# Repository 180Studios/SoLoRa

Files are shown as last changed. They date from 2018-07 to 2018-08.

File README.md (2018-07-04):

Board Features:

1. Low-cost components 

2. Easy (ish) Assembly. 
    a. Uses QFP package processor and 0603 Rs and Cs 
    b. Can be soldered by hand by most people using standard soldering iron 
    c. One exception is the accelerometer, which can be soldered using a reflow heat gun and a little training

3. Arduino compatible 
    a. Uses the same device as the Arduino Zero - can use Arduino bootloader. 

4. FeatherWing compatible 
    a. Can use with Adafruit’s featherwing expansion boards or use the header for a protoboard mezzanine 

5. Multiple power options to targeting wider IoT applications, particular field applications 
    a. Solar 
        i. Has a CR123 battery clip for a LiFePo4 battery used as a power reservoir. (400mAh) 
        ii. On-board regulator charges LiFePo4 to constant voltage. Solar cell size constrains max charge current. 
    b. Rechargeable Li-Po or external battery pack 
        i. For standard indoor applications 
        ii. On-board USB micro connector and charger IC 
    c. Lithium (primary cell) 
        i. Battery clip will also house a standard CR123 3V Lithium, which has ~1000mAH capacity 
    d. USB 5V for desktop development (or use with a USB battery bank?) 
    e. On- board adjustable regulator 
        i. Change Resistor values to adjust VDD 
            1. To drop Li-Po, external battery pack output voltage and USB 5V to safe level 
            2. LiFePo4 charge voltage. 
        ii. Regulator is used with Lithium primary battery 

6. Small size: 2.3 x 2 inches 
    a. Has mounting holes to match a inexpensive water tight enclosure 
    b. All components mount on one-size only. Bottom is free to increase mounting versatility. 
    c. 2-layer board, cheaper to fabricate. 

7. ARM Cortex M0 (SAMD20G18A) 

    a. Low power, high speed capable, 256K Flash 

8. Optional on-board sensors, indicators 
    a. 3-Axis Accelerometer 
    b. Temperature 
    c. Programmable Red LED 

9. Development Options 
    a. Arduino IDE (use as an Arduino Zero) 
    b. Atmel Studio 
        i. Atmel Studio has Arduino templates to program like Arduino, or: 
        ii. Use standard C form 
        iii. Full debugging capability (breakpoints, watch variables) 
            1. $20 JTAG debugger hardware required for this feature

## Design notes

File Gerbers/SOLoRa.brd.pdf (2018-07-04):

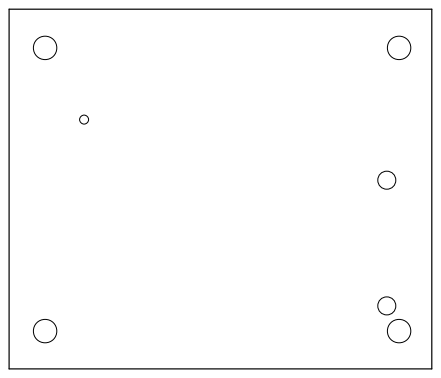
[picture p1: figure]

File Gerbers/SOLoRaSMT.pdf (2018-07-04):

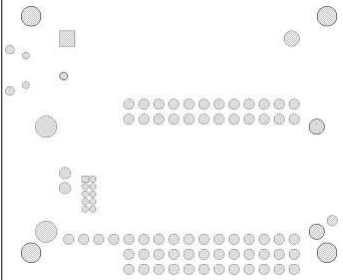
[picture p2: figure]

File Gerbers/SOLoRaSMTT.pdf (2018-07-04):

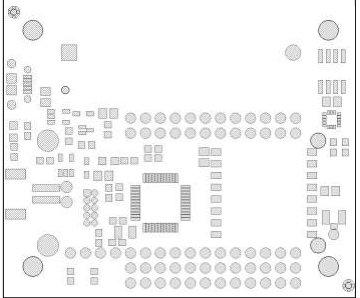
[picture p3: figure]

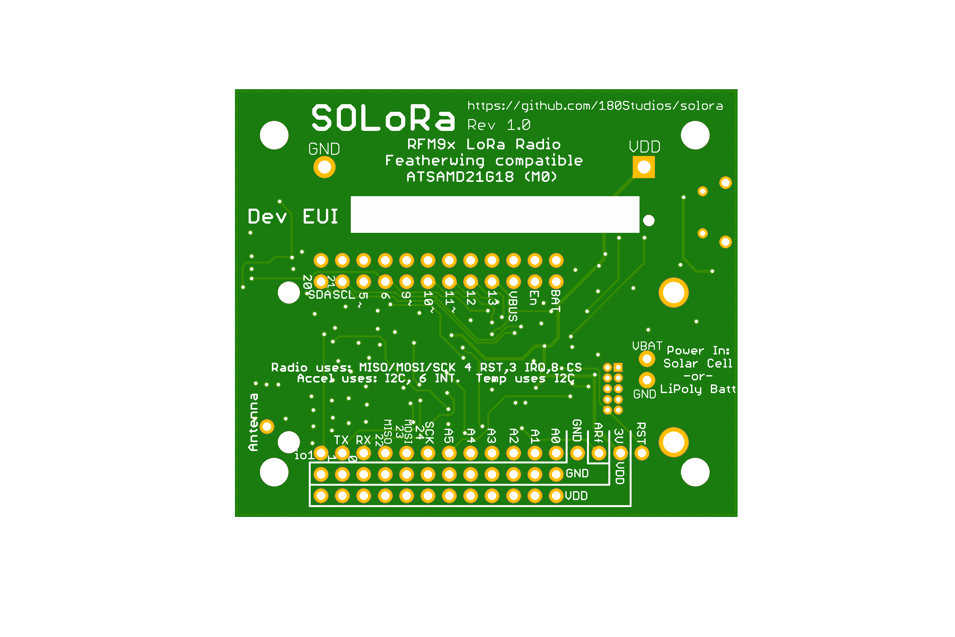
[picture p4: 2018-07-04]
Documentation/SOLoRa_BottomView.png

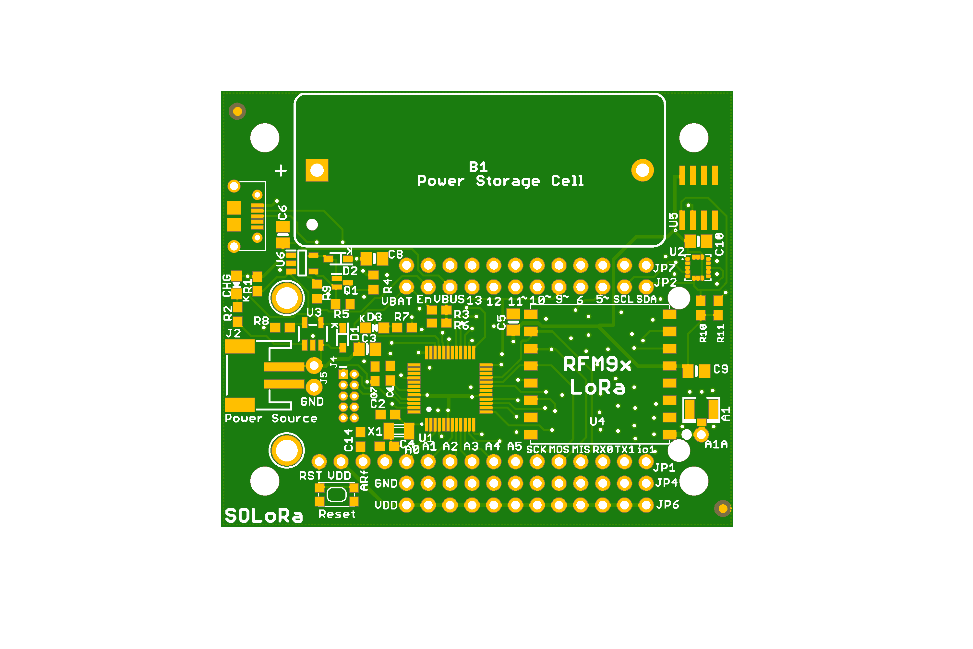
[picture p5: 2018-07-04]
Documentation/SOLoRa_TopView.png

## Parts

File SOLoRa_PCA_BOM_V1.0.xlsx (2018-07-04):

Part | Value | Device | Package | Description | BOM | DESCRIPTION | DIGI-KEY_PART_NUMBER | DIGI-KEY_PURCHASE_URL | HEIGHT | MANUFACTURER_NAME | MANUFACTURER_PART_NUMBER
A1 | U.FL Conn | ANTENNA_U.FL | U.FL | U.FL Antenna Connector
A1A | Pad for wire antenna | HEADER-1X1ROUND | 1X01_ROUND | PIN HEADER
B1 | BH123A | BH123A | BH123A
C1 | 1uF | CAP_CERAMIC0603_NO | 0603-NO | Ceramic Capacitors
C2 | 22pF | CAP_CERAMIC0603_NO | 0603-NO | Ceramic Capacitors
C3 | 10ÂµF | CAP_CERAMIC0805-NOOUTLINE | 0805-NO | Ceramic Capacitors
C4 | 22pF | CAP_CERAMIC0603_NO | 0603-NO | Ceramic Capacitors
C5 | 10uF | CAP_CERAMIC0805-NOOUTLINE | 0805-NO | Ceramic Capacitors
C6 | 10ÂµF | CAP_CERAMIC0805-NOOUTLINE | 0805-NO | Ceramic Capacitors
C7 | 1uF | CAP_CERAMIC0603_NO | 0603-NO | Ceramic Capacitors
C8 | 10ÂµF | CAP_CERAMIC0805-NOOUTLINE | 0805-NO | Ceramic Capacitors
C9 | 10uF | CAP_CERAMIC0805-NOOUTLINE | 0805-NO | Ceramic Capacitors
C10 | 10uF | CAP_CERAMIC0805-NOOUTLINE | 0805-NO | Ceramic Capacitors
C14 | 1uF | CAP_CERAMIC0603_NO | 0603-NO | Ceramic Capacitors
CHG | ORANGE | LED0805_NOOUTLINE | CHIPLED_0805_NOOUTLINE | LED
D1 | CUS520,H3F | CUS520,H3F | SOD2513X135N | Schottky Barrier Diode Silicon Epitaxial,Single Low Leakge, 30V 200mA Surface Mount USC |  | Schottky Barrier Diode Silicon Epitaxial,Single Low Leakge, 30V 200mA Surface Mount USC |  |  | 1.35mm | Toshiba | CUS520,H3F
D2 | CUS520,H3F | CUS520,H3F | SOD2513X135N | Schottky Barrier Diode Silicon Epitaxial,Single Low Leakge, 30V 200mA Surface Mount USC |  | Schottky Barrier Diode Silicon Epitaxial,Single Low Leakge, 30V 200mA Surface Mount USC |  |  | 1.35mm | Toshiba | CUS520,H3F
D3 | RED | LED0805_NOOUTLINE | CHIPLED_0805_NOOUTLINE | LED
H1 | STAND-OFF | STAND-OFF | STAND-OFF | Stand Off
H2 | STAND-OFF | STAND-OFF | STAND-OFF | Stand Off
H3 | STAND-OFF | STAND-OFF | STAND-OFF | Stand Off
H4 | STAND-OFF | STAND-OFF | STAND-OFF | Stand Off
J1 | CONN_USB-MIRCO_10118194 | CONN_USB-MIRCO_10118194 | 10118194_USB | CONN USB Micro Receptical SMT & PTH R/A Ampenol FCI 10118194-001LF
J2 | JSTPH | CON_JST_PH_2PIN | JSTPH2 | JST 2-Pin Right-Angle Connector
J4 | CORTEX_DEBUG_PTH | CORTEX_DEBUG_PTH | 2X5-PTH-1.27MM | Cortex Debug Connector - 10 pin
J5 |  | CONN_021X02_NO_SILK | 1X02_NO_SILK | Multi connection point. Often used as Generic Header-pin footprint for 0.1 inch spaced/style header connections
JP1 |  | HEADER-1X16ROUND | 1X16_ROUND | PIN HEADER
JP2 |  | HEADER-1X12 | 1X12_ROUND
JP4 |  | HEADER-1X12 | 1X12_ROUND
JP6 |  | HEADER-1X12 | 1X12_ROUND
JP7 |  | HEADER-1X12 | 1X12_ROUND
Q1 | RE1C002UNTCL | RE1C002UNTCL | SOT50P160X85-3N | MOSFET 1.2V Drive Nch MOSFET |  | MOSFET 1.2V Drive Nch MOSFET |  |  | 0.85mm | ROHM Semiconductor | RE1C002UNTCL
R1 | 100k | RESISTOR_0603_NOOUT | 0603-NO | Resistors
R2 | 1K | RESISTOR_0603_NOOUT | 0603-NO | Resistors
R3 | 220k | RESISTOR_0603_NOOUT | 0603-NO | Resistors
R4 | 383K | R-US_R0603 | R0603 | RESISTOR, American symbol
R5 | 133K | R-US_R0603 | R0603 | RESISTOR, American symbol
R6 | 100K | RESISTOR_0603_NOOUT | 0603-NO | Resistors
R7 | 2.2K | RESISTOR_0603_NOOUT | 0603-NO | Resistors
R8 | 22k | RESISTOR_0603_NOOUT | 0603-NO | Resistors
R9 | 220K | R-US_R0603 | R0603 | RESISTOR, American symbol
R10 | 2.2K | RESISTOR_0603_NOOUT | 0603-NO | Resistors
R11 | 2.2K | RESISTOR_0603_NOOUT | 0603-NO | Resistors
S1 | SPST_TACT-KMR2 | SPST_TACT-KMR2 | KMR2 | SMT 6mm switch, EVQQ2 series
U$31 | MOUNTINGHOLE2.5 | MOUNTINGHOLE2.5 | MOUNTINGHOLE_2.5_PLATED | Mounting Hole | EXCLUDE
U$32 | MOUNTINGHOLE2.5 | MOUNTINGHOLE2.5 | MOUNTINGHOLE_2.5_PLATED | Mounting Hole | EXCLUDE
U$34 | FIDUCIAL" | FIDUCIAL" | FIDUCIAL_1MM | Fiducial Alignment Points | EXCLUDE
U$35 | FIDUCIAL" | FIDUCIAL" | FIDUCIAL_1MM | Fiducial Alignment Points | EXCLUDE
U1 | ATSAMD21G18A-AUT | ATSAMD21G18A-AUT | QFP50P900X900X120-48N | Cortex-M0+, 256KB FLASH, 32KB SRAM, USB, DMA, T&R - 48TQFP IND TEMP, GREEN, 1.6-3.6V, 48MHz |  | MCU 32-bit SAM D21 ARM Cortex M0+ RISC 256KB Flash 3.3V 48-Pin TQFP T/R | ATSAMD21G18A-AUTCT-ND | https://www.digikey.com/product-detail/en/microchip-technology/ATSAMD21G18A-AUT/ATSAMD21G18A-AUTCT-ND/4878879
U2 | LIS3DETR | LIS3DETR | LGA16R50P5X3_300X300X100N | MEMS digital output motion sensor ultra low-power high performance 3-axes nano" accelerometer" |  | MEMS digital output motion sensor ultra low-power high performance 3-axes nano accelerometer | 497-16262-1-ND | https://www.digikey.com/product-detail/en/stmicroelectronics/LIS3DETR/497-16262-1-ND/5799914
U3 | MCP73831T-2ACI/OT | MCP73831/2 | SOT23-5 | MCP73831/2 LIPO Charger
U4 | RFM69HCW | RFM69HCW_SMT | RFMHCW_SMT | RFM69HCW - ISM Band RF Transceiver
U5 | LM75 | LM75 | SO8
U6 | NCP718ASNADJT1G | NCP718ASNADJT1G | SOT95P280X100-5N | LDO Regulator, 300 mA, Low Iq, Wide Input Voltage Adjustable, Active Discharge |  | LDO Regulator, 300 mA, Low Iq, Wide Input Voltage Adjustable, Active Discharge |  |  | 1mm | ON Semiconductor | NCP718ASNADJT1G
X1 | 32.768 | XTAL-3.2X1.5 | XTAL3215 | Low cost SMT crystals, no capacitors included

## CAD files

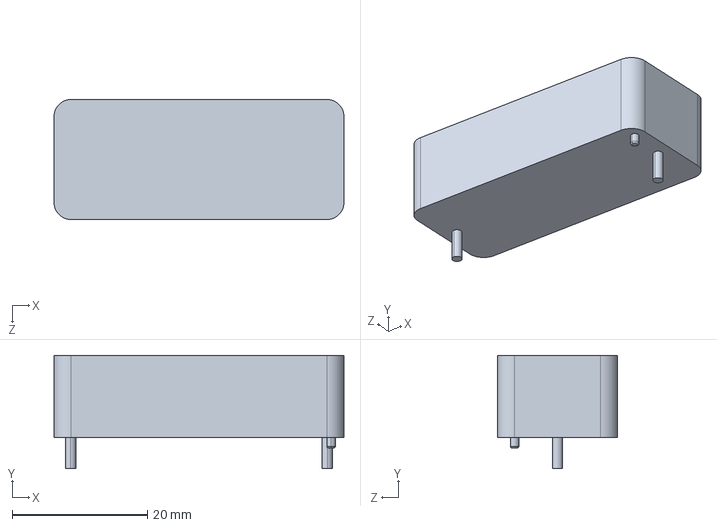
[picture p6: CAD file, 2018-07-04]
Documentation/Datasheets/BH123A.STEP
42.9 x 16.8 x 17.8 mm

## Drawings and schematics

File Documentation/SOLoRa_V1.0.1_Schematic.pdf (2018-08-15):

A

A

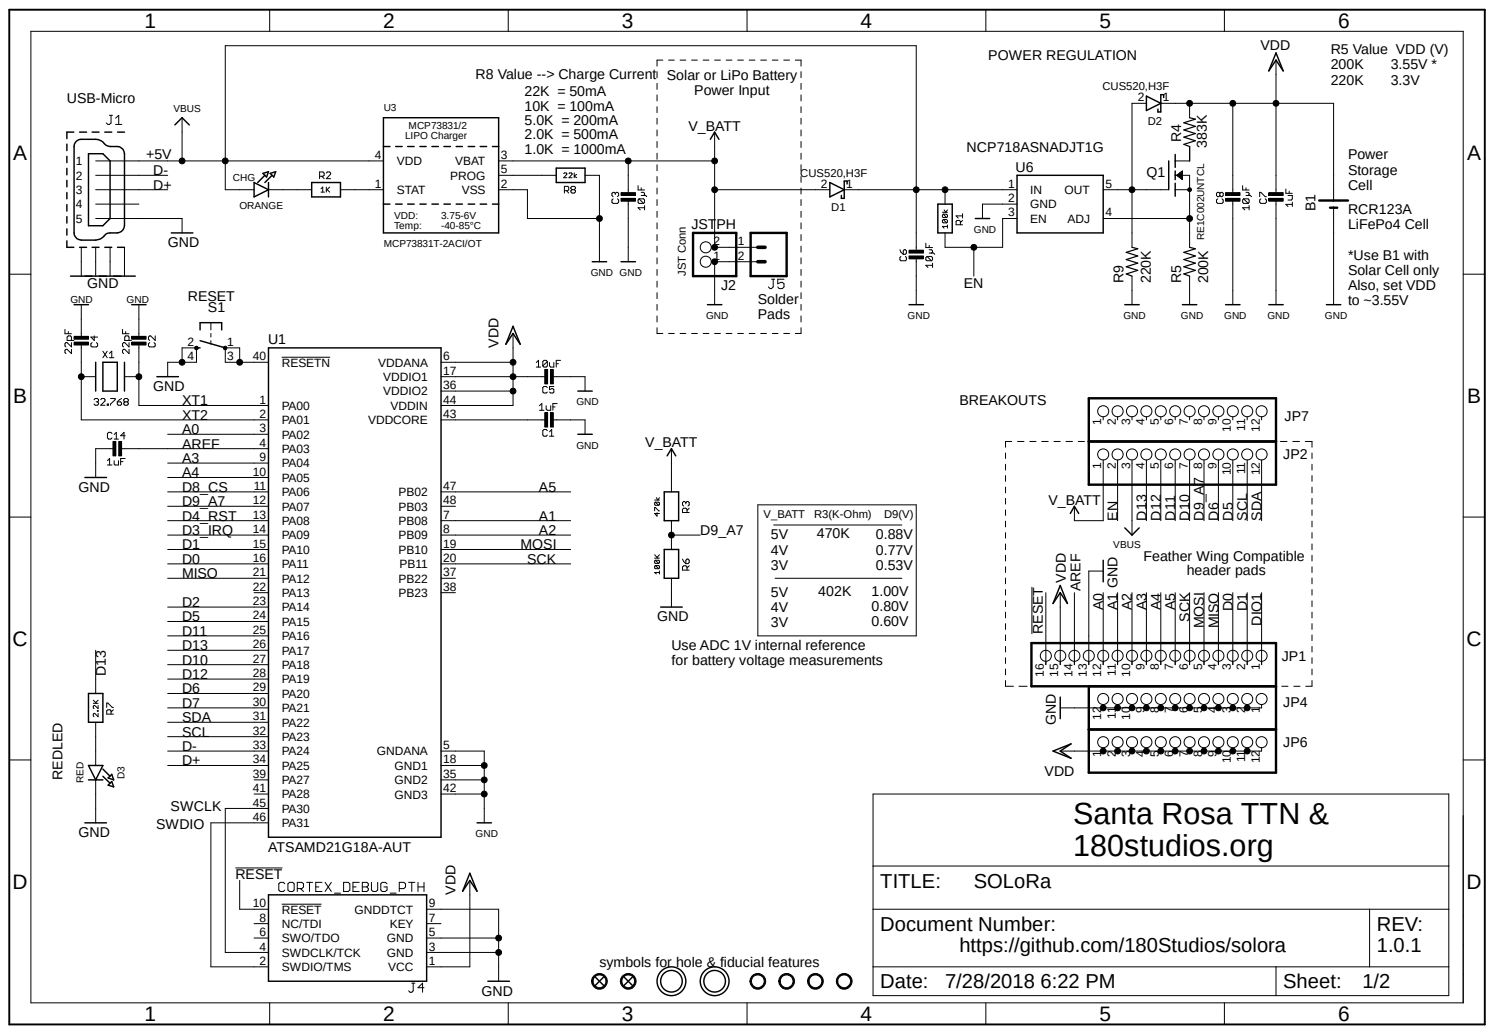
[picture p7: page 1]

Solar or LiPo Battery
Power Input

Use ADC 1V internal reference
for battery voltage measurements

Document Number: https://github.com/180Studios/solora | REV: 1.0.1

symbols for hole & fiducial features

Date: 7/28/2018 6:22 PM | Sheet: 1/2

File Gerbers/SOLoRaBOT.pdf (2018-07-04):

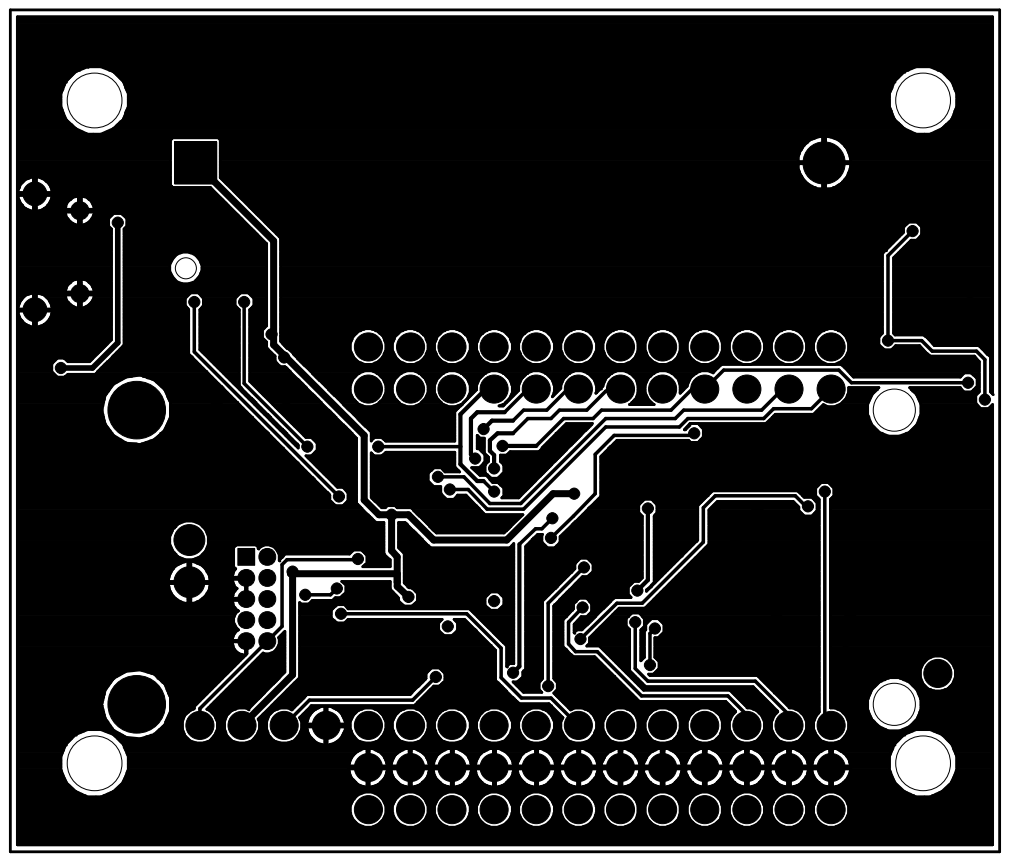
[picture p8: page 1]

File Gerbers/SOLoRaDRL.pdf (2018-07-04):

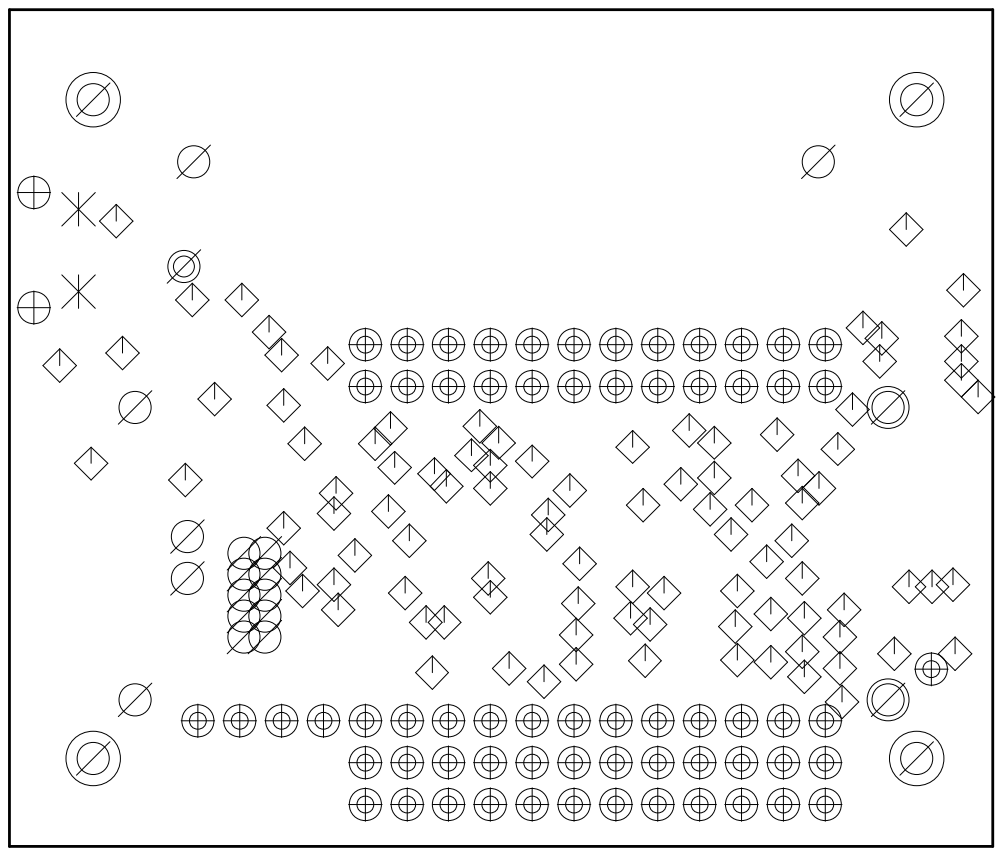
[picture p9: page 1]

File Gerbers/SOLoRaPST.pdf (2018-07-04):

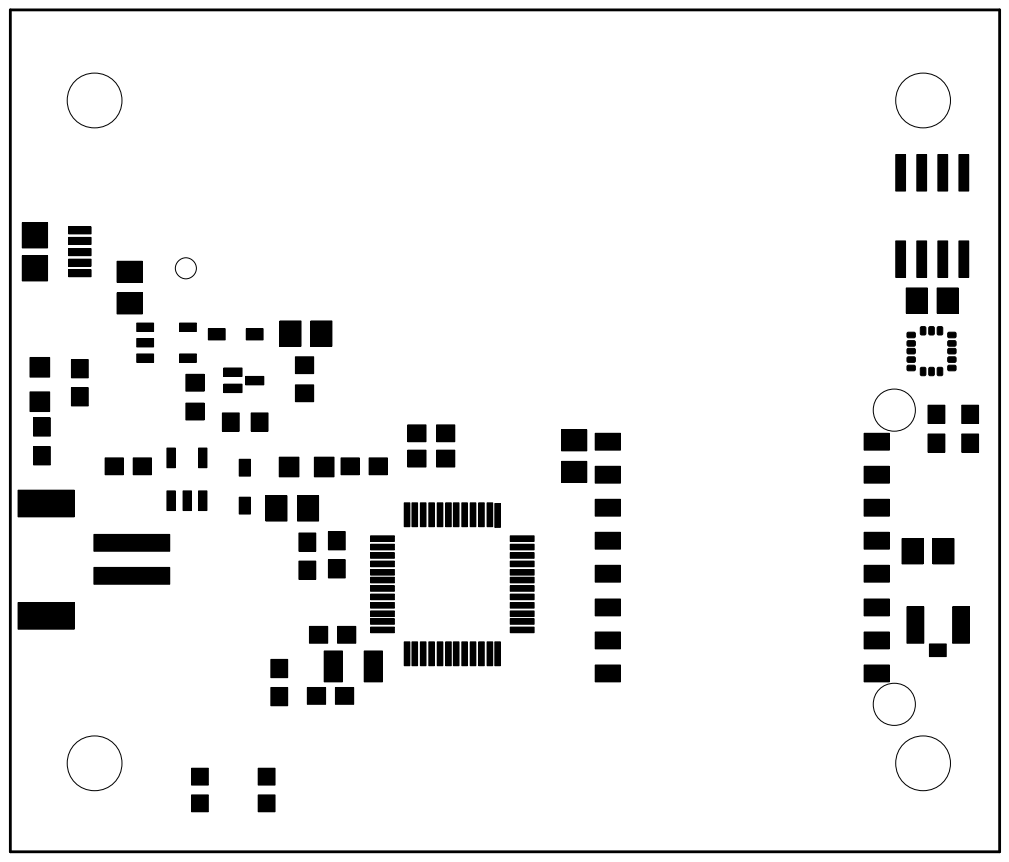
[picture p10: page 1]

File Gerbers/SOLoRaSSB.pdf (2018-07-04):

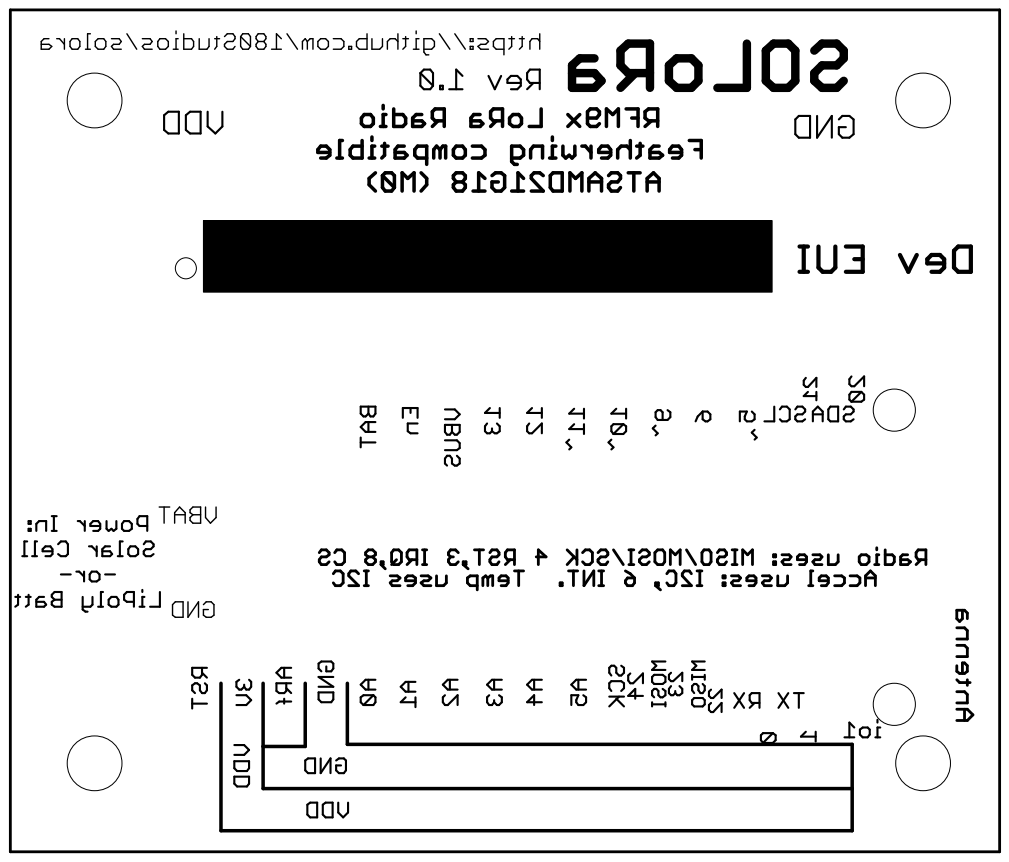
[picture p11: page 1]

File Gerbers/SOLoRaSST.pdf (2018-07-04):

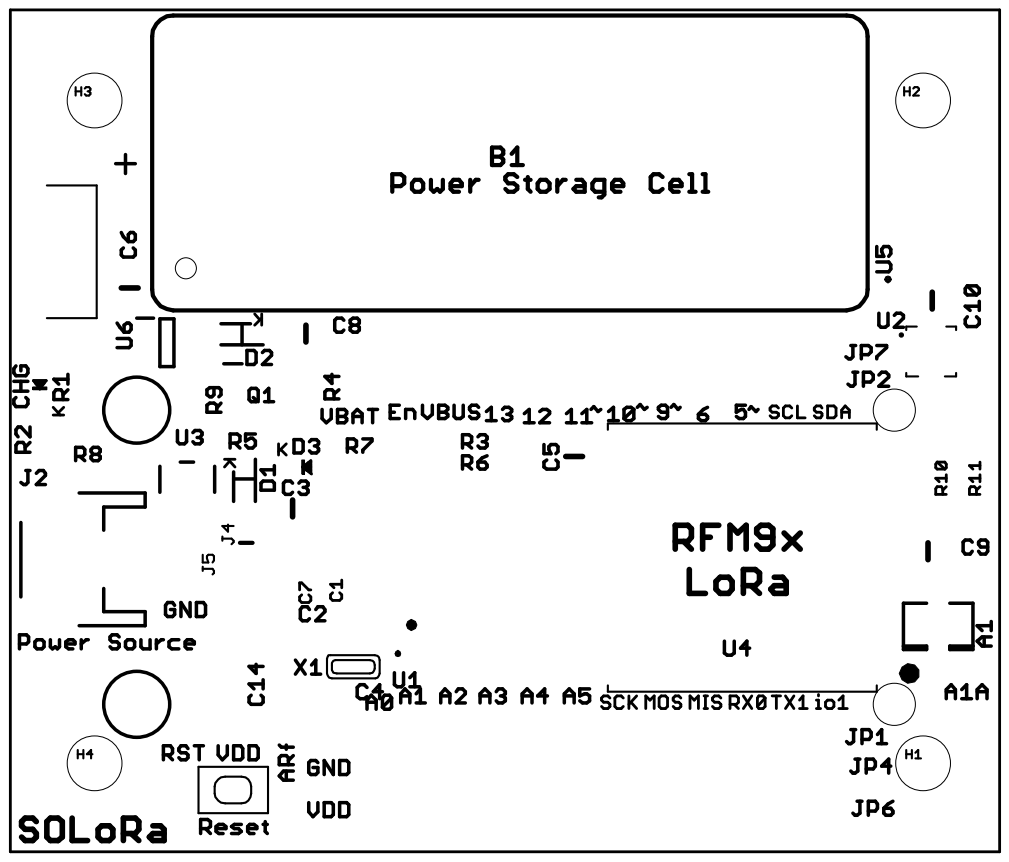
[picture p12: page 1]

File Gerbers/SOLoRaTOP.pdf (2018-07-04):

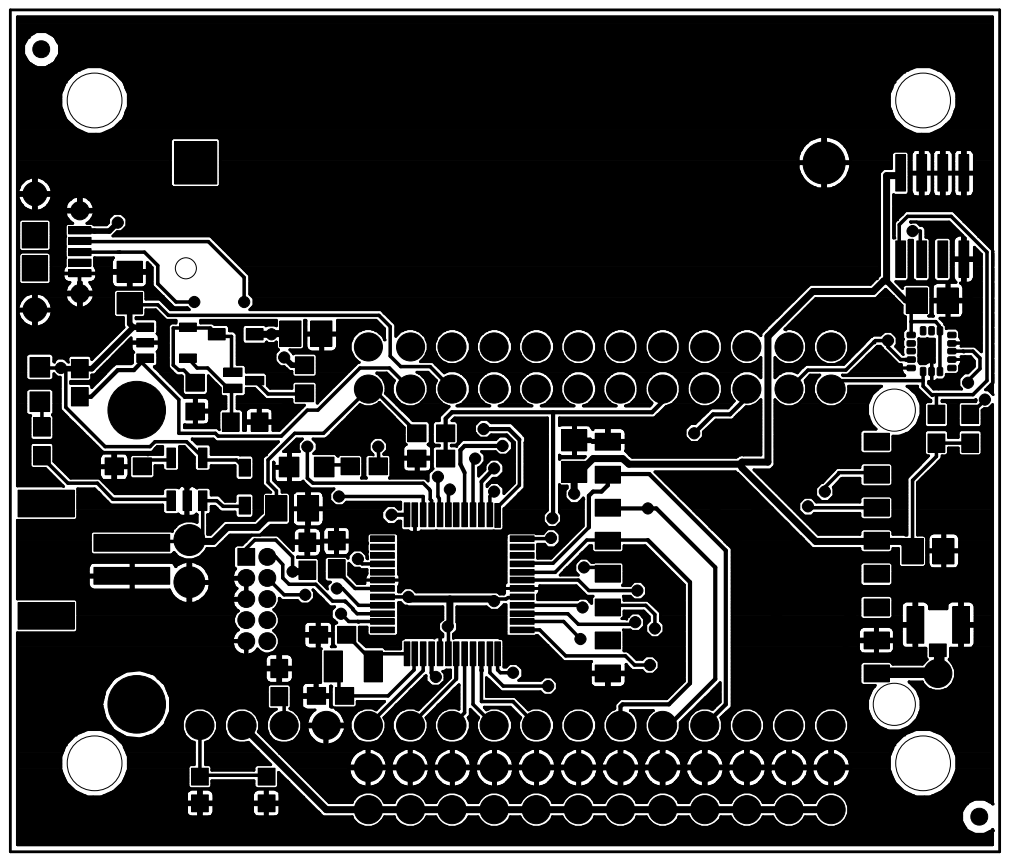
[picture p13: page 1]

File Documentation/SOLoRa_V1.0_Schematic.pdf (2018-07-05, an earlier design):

A

1 | 2 | 3 | 4 | 5 | 6

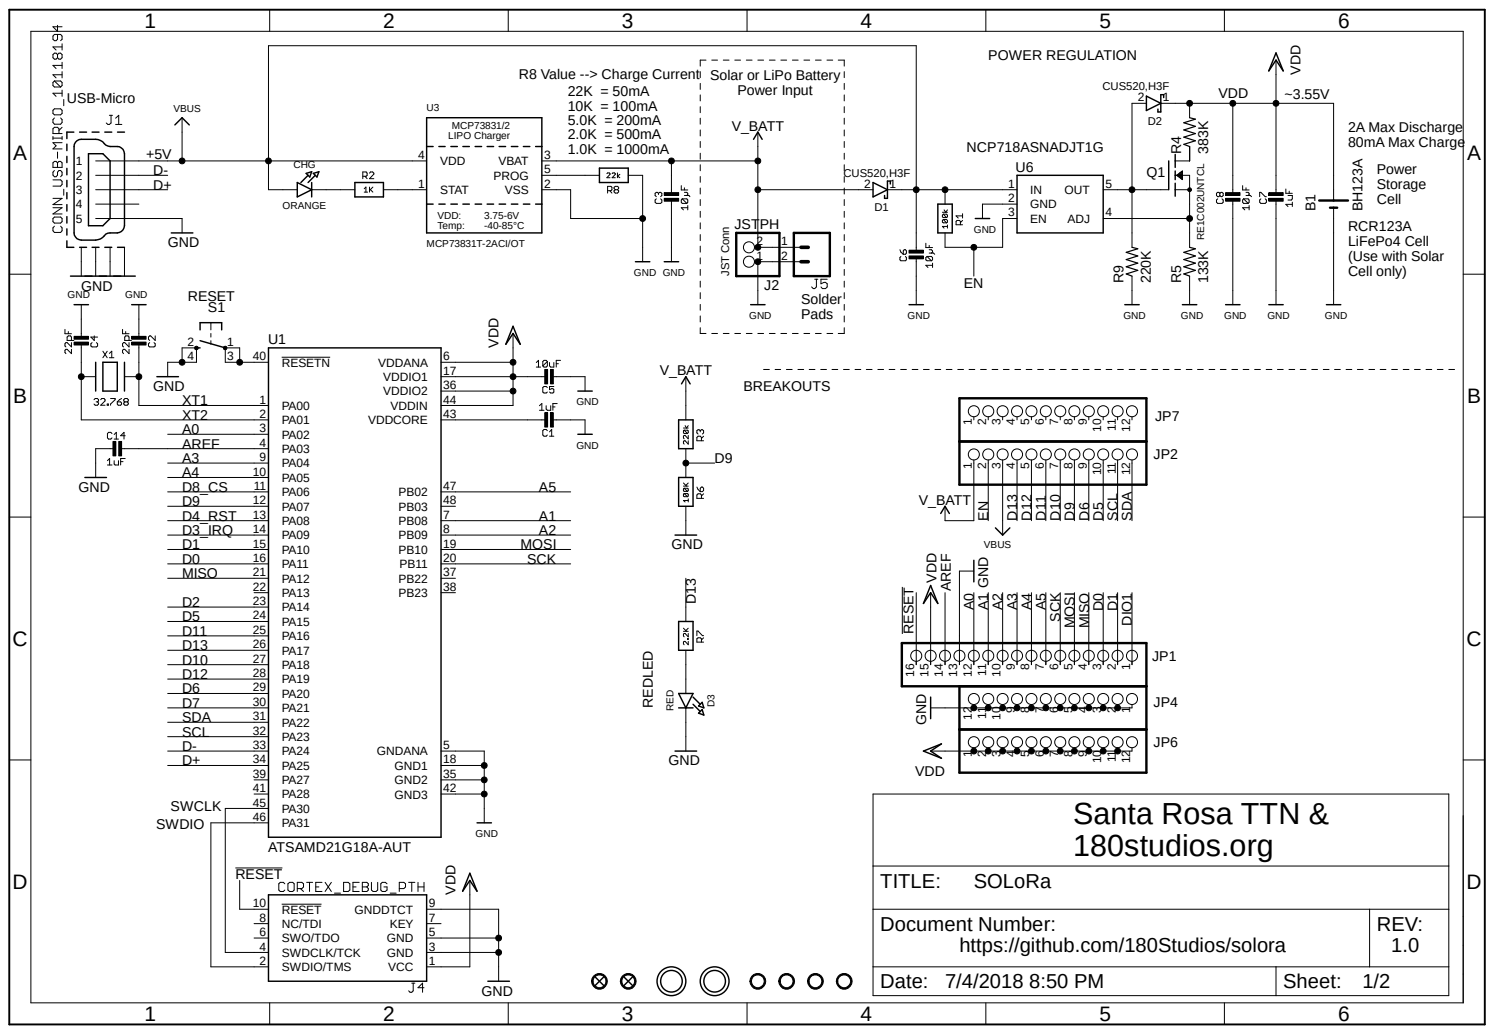
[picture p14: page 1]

Solar or LiPo Battery
Power Input

Document Number: https://github.com/180Studios/solora | REV: 1.0

Date: 7/4/2018 8:50 PM | Sheet: 1/2

## ABCD

## ABCD

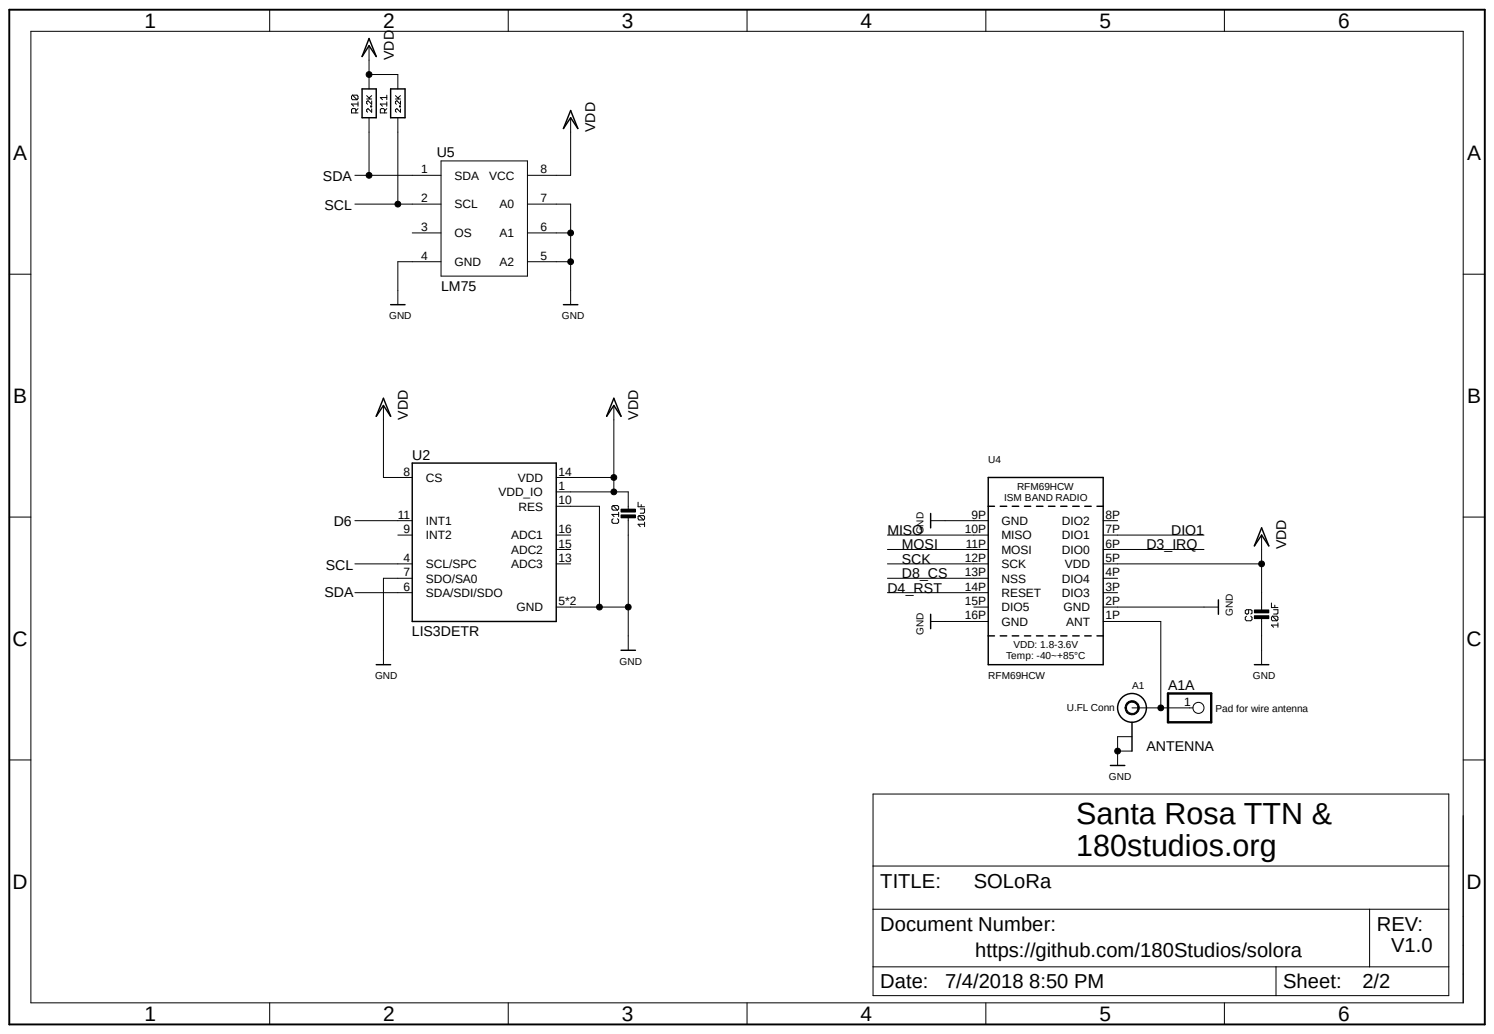
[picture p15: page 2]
GND; VDD; U.FL Conn; LIS3DETR; GND VDD; MISO 10P; DIO0; DIO2; DIO1; DIO5 15P; RESET 14P; GND 16P; ANT; 1P GND; 2P DIO3; MOSI 11P SCK 12P NSS 13P; RFM69HCW; DIO4; 4P VDD; GND 9P; VDD_IO; SCL/SPC; 5*2 SDA/SDI/SDO; SDO/SA0 7; INT2; RES; INT1 11; ADC3; ADC2; 15 ADC1; SDA; SCL; VCC; MOSI; MISO; SCK; D3_IRQ; D4_RST; RFM69HCW ISM BAND RADIO; VDD: 1.8-3.6V Temp: -40~+85°C; TITLE:; SOLoRa; ANTENNA

Pad for wire antenna

GND
Santa Rosa TTN &
180studios.org

Document Number: https://github.com/180Studios/solora | REV: V1.0

Date: 7/4/2018 8:50 PM | Sheet: 2/2

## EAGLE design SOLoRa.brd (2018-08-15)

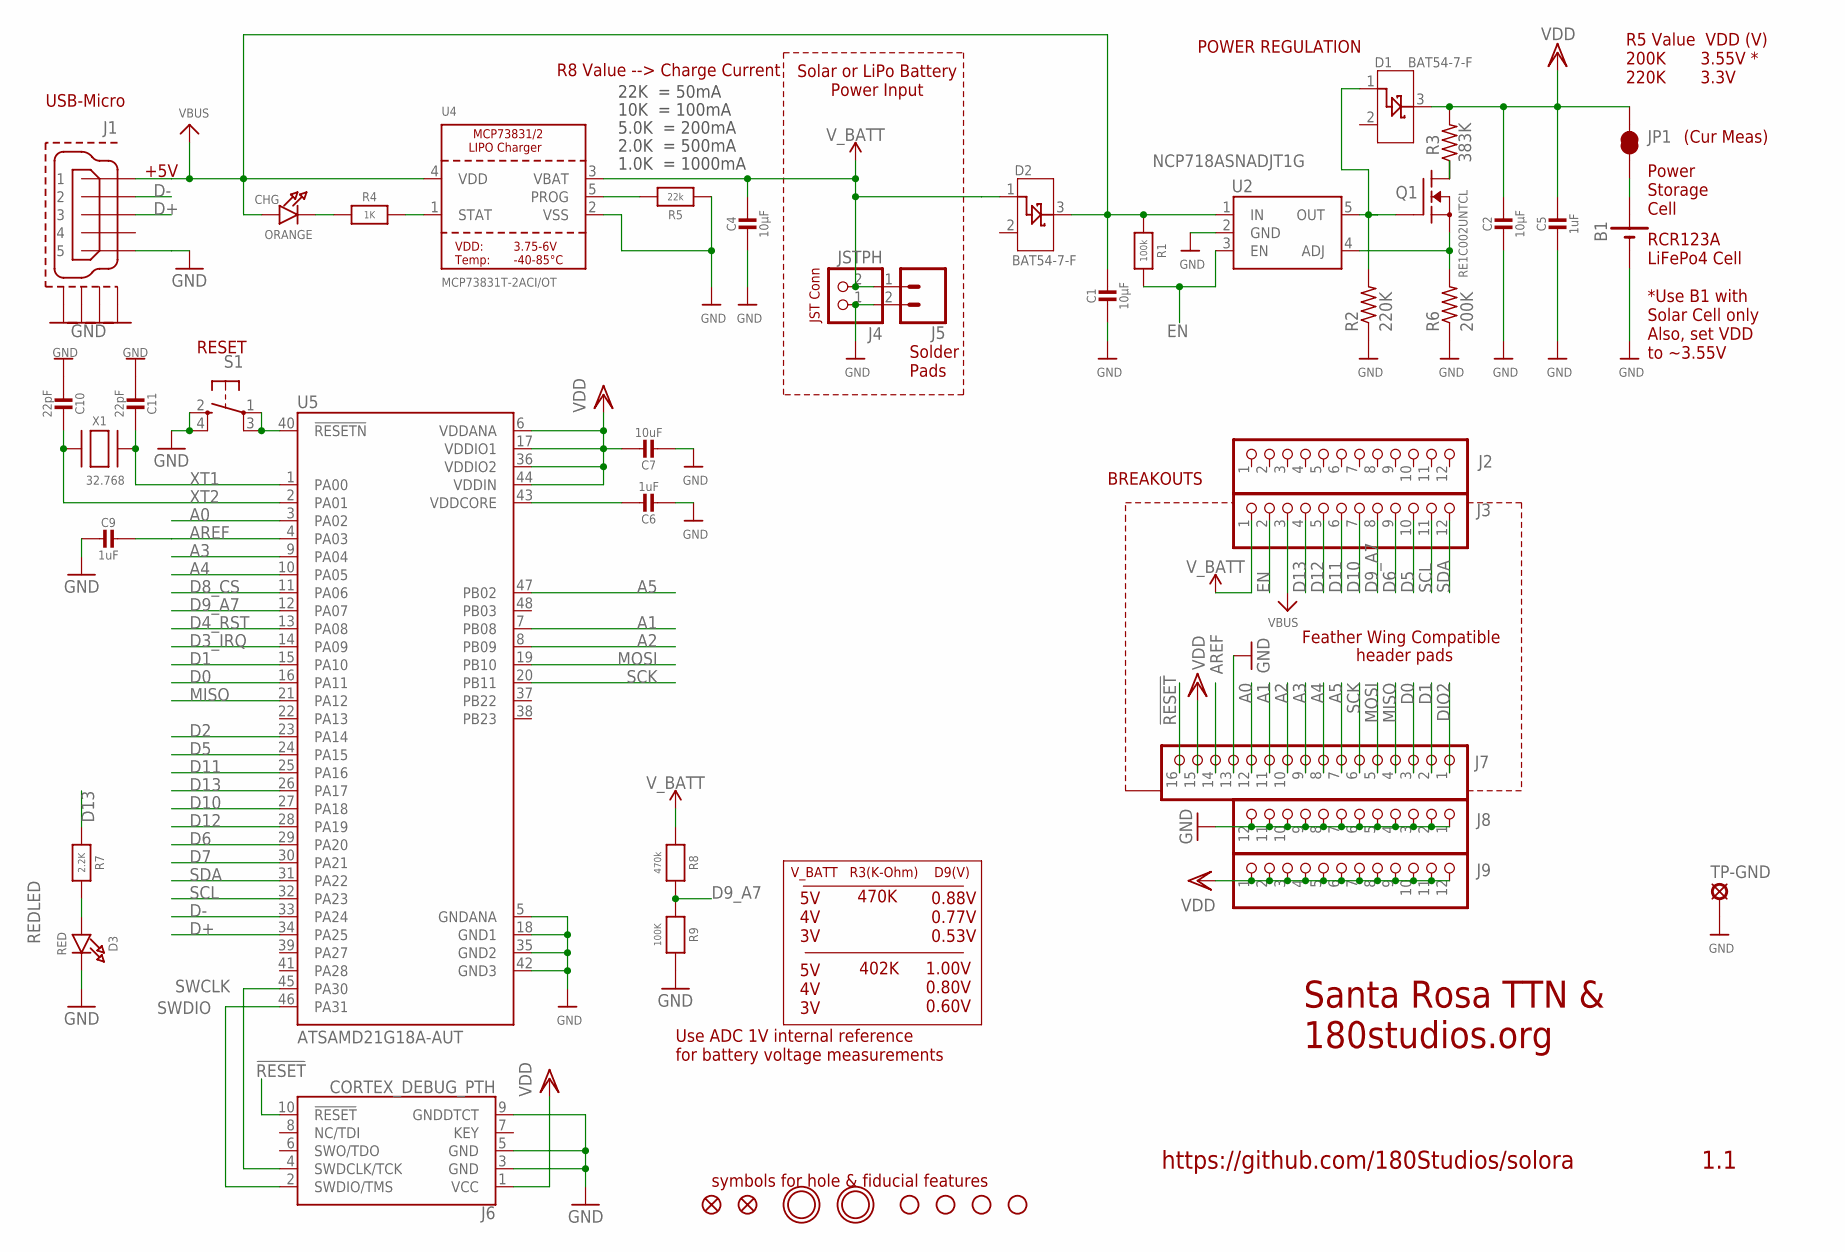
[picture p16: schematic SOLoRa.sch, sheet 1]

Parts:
$$U$1, $$U$4: FIDUCIAL""; FIDUCIAL_1MM
$$U$2, $$U$3: MOUNTINGHOLE2.5; MOUNTINGHOLE_2.5_PLATED
B1: BH123A
C1, C2, C4: 10µF; 0805-NO
C5, C6, C9: 1uF; 0603-NO
C7: 10uF; 0805-NO
C10, C11: 22pF; 0603-NO
CHG: ORANGE; CHIPLED_0805_NOOUTLINE
D1, D2: BAT54-7-F; SOT-23
D3: RED; CHIPLED_0805_NOOUTLINE
H1, H2, H3, H4: STAND-OFF
J1: CONN_USB-MIRCO_10118194; 10118194_USB
J2, J3, J8, J9: HEADER-1X12; 1X12_ROUND
J4: JSTPH; JSTPH2
J5: CONN_021X02_NO_SILK; 1X02_NO_SILK
J6: CORTEX_DEBUG_PTH; 2X5-PTH-1.27MM
J7: HEADER-1X16ROUND; 1X16_ROUND
JP1: JUMPER-SMT_2_NC_TRACE_NO-SILK; SMT-JUMPER_2_NC_TRACE_NO-SILK
Q1: RE1C002UNTCL; SOT50P160X85-3N
R1: 100k; 0603-NO
R2: 220K; R0603
R3: 383K; R0603
R4: 1K; 0603-NO
R5: 22k; 0603-NO
R6: 200K; R0603
R7: 2.2K; 0603-NO
R8: 470k; 0603-NO
R9: 100K; 0603-NO
S1: SPST_TACT-KMR2; KMR2
TP-GND: SE14
U2: NCP718ASNADJT1G; SOT95P280X100-5N
U4: MCP73831T-2ACI/OT; SOT23-5
U5: ATSAMD21G18A-AUT; QFP50P900X900X120-48N
X1: 32.768; XTAL3215

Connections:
!RESET: J6.10 (!RESET), J7.16, S1.1, S1.3 (P1), U5.40 (!RESETN)
A0: J7.12, U5.3 (PA02)
A1: J7.11, U5.7 (PB08)
A2: J7.10, U5.8 (PB09)
A3: J7.9, U5.9 (PA04)
A4: J7.8, U5.10 (PA05)
A5: J7.7, U5.47 (PB02)
ADJ1: Q1.3 (D), R3.1
AREF: C9.1, J7.14, U5.4 (PA03)
CHGLED: CHG.C, R4.1
D0: J7.3, U5.16 (PA11)
D1: J7.2, U5.15 (PA10)
D2: U5.23 (PA14)
D3_IRQ: U5.14 (PA09); also elsewhere on the board
D4_RST: U5.13 (PA08); also elsewhere on the board
D5: J3.10, U5.24 (PA15)
D6: J3.9, U5.29 (PA20); also elsewhere on the board
D7: U5.30 (PA21)
D8_CS: U5.11 (PA06); also elsewhere on the board
D9_A7: J3.8, R8.2, R9.1, U5.12 (PA07)
D10: J3.7, U5.27 (PA18)
D11: J3.6, U5.25 (PA16); also elsewhere on the board
D12: J3.5, U5.28 (PA19)
D13: J3.4, R7.1, U5.26 (PA17)
D+: J1.3, U5.34 (PA25)
D-: J1.2, U5.33 (PA24)
DIO2: J7.1; also elsewhere on the board
EN: J3.2, R1.2, U2.3 (EN)
GND: B1.MINUS, C1.2, C2.2, C4.2, C5.2, C6.2, C7.2, C9.2, C10.2, C11.2, D3.C, J1.5, J1.6 (GND1), J1.7 (GND2), J1.8 (GND3), J1.9 (GND4), J4.1, J5.2, J6.3 (GND), J6.5 (GND), J6.9 (GNDDTCT), J7.13, J8.1, J8.2, J8.3, J8.4, J8.5, J8.6, J8.7, J8.8, J8.9, J8.10, J8.11, J8.12, R2.1, R5.2, R6.1, R9.2, S1.2 (S), S1.4 (S1), TP-GND.MP, U2.2 (GND), U4.2 (VSS), U5.5 (GNDANA), U5.18 (GND1), U5.35 (GND2), U5.42 (GND3); also elsewhere on the board
MISO: J7.4, U5.21 (PA12); also elsewhere on the board
MOSI: J7.5, U5.19 (PB10); also elsewhere on the board
PLUS: B1.PLUS, JP1.1
PROG: R5.1, U4.5 (PROG)
REDLED: D3.A, R7.2
REGADJ: Q1.2 (S), R6.2, U2.4 (ADJ)
REGOUT: D1.1 (EPAD1), Q1.1 (G), R2.2, U2.5 (OUT)
SCK: J7.6, U5.20 (PB11); also elsewhere on the board
SCL: J3.11, U5.32 (PA23); also elsewhere on the board
SDA: J3.12, U5.31 (PA22); also elsewhere on the board
STAT: R4.2, U4.1 (STAT)
SWCLK: J6.4 (SWDCLK/TCK), U5.45 (PA30)
SWDIO: J6.2 (SWDIO/TMS), U5.46 (PA31)
VBUS: C1.1, CHG.A, D2.3 (EPAD3), J1.1, J3.3, R1.1, U2.1 (IN), U4.4 (VDD)
VDD: C2.1, C5.1, C7.1, D1.3 (EPAD3), J6.1 (VCC), J7.15, J9.1, J9.2, J9.3, J9.4, J9.5, J9.6, J9.7, J9.8, J9.9, J9.10, J9.11, J9.12, JP1.2, R3.2, U5.6 (VDDANA), U5.17 (VDDIO1), U5.36 (VDDIO2), U5.44 (VDDIN); also elsewhere on the board
VDDCORE: C6.1, U5.43 (VDDCORE)
V_BATT: C4.1, D2.1 (EPAD1), J3.1, J4.2, J5.1, R8.1, U4.3 (VBAT)
XT1: C11.1, U5.1 (PA00), X1.P$1
XT2: C10.1, U5.2 (PA01), X1.P$2

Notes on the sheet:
POWER REGULATION
RESET
10K = 100mA
5.0K = 200mA
2.0K = 500mA
1.0K = 1000mA
BREAKOUTS
R5 Value VDD (V) 200K 3.55V * 220K 3.3V
22K = 50mA
RCR123A LiFePo4 Cell *Use B1 with Solar Cell only Also, set VDD to ~3.55V
Solar or LiPo Battery Power Input
Power Storage Cell
JST Conn
Solder Pads
R8 Value --> Charge Current
1.1
Santa Rosa TTN & 180studios.org
https://github.com/180Studios/solora
USB-Micro
+5V
Feather Wing Compatible
header pads
V_BATT R3(K-Ohm) D9(V)
5V 4V 3V
470K
402K
0.88V 0.77V 0.53V
1.00V 0.80V 0.60V
Use ADC 1V internal reference for battery voltage measurements
symbols for hole & fiducial features
(Cur Meas)

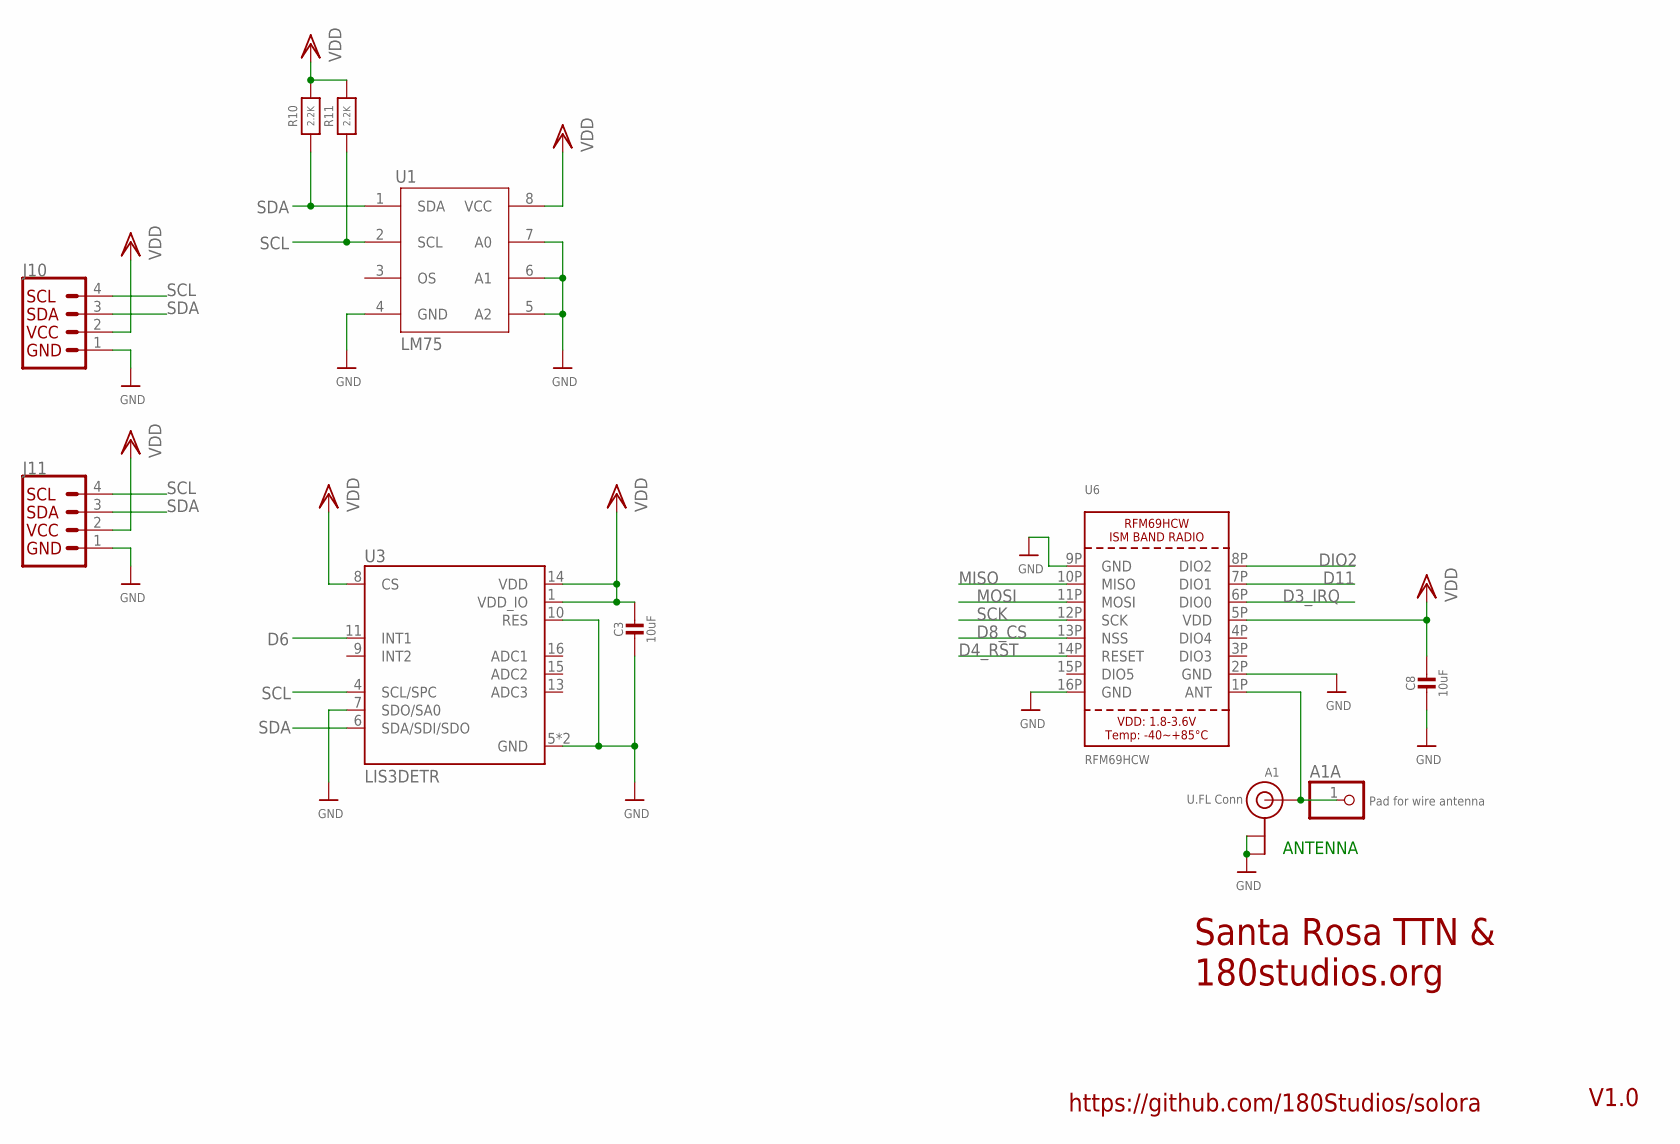
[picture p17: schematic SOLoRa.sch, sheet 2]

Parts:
A1: U.FL Conn; U.FL
A1A: Pad for wire antenna; 1X01_ROUND
C3, C8: 10uF; 0805-NO
J10, J11: QWIIC_CONNECTORJS-1MM; 1X04_1MM_RA
R10, R11: 2.2K; 0603-NO
U1: LM75; SO8
U3: LIS3DETR; LGA16R50P5X3_300X300X100N
U6: RFM69HCW; RFMHCW_SMT

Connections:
ANT: A1.3 (SIGNAL), A1A.1, U6.1P (ANT)
D3_IRQ: U6.6P (DIO0); also elsewhere on the board
D4_RST: U6.14P (RESET); also elsewhere on the board
D6: U3.11 (INT1); also elsewhere on the board
D8_CS: U6.13P (NSS); also elsewhere on the board
D11: U6.7P (DIO1); also elsewhere on the board
DIO2: U6.8P (DIO2); also elsewhere on the board
GND: A1.1 (GND), A1.2 (GND), C3.2, C8.2, J10.1, J11.1, U1.4 (GND), U1.5 (A2), U1.6 (A1), U1.7 (A0), U3.5 (GND), U3.7 (SDO/SA0), U3.10 (RES), U3.12 (GND), U6.2P (GND), U6.9P (GND), U6.16P (GND); also elsewhere on the board
MISO: U6.10P (MISO); also elsewhere on the board
MOSI: U6.11P (MOSI); also elsewhere on the board
SCK: U6.12P (SCK); also elsewhere on the board
SCL: J10.4, J11.4, R11.1, U1.2 (SCL), U3.4 (SCL/SPC); also elsewhere on the board
SDA: J10.3, J11.3, R10.1, U1.1 (SDA), U3.6 (SDA/SDI/SDO); also elsewhere on the board
VDD: C3.1, C8.1, J10.2, J11.2, R10.2, R11.2, U1.8 (VCC), U3.1 (VDD_IO), U3.8 (CS), U3.14 (VDD), U6.5P (VDD); also elsewhere on the board

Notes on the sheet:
ANTENNA
Santa Rosa TTN & 180studios.org
V1.0
https://github.com/180Studios/solora

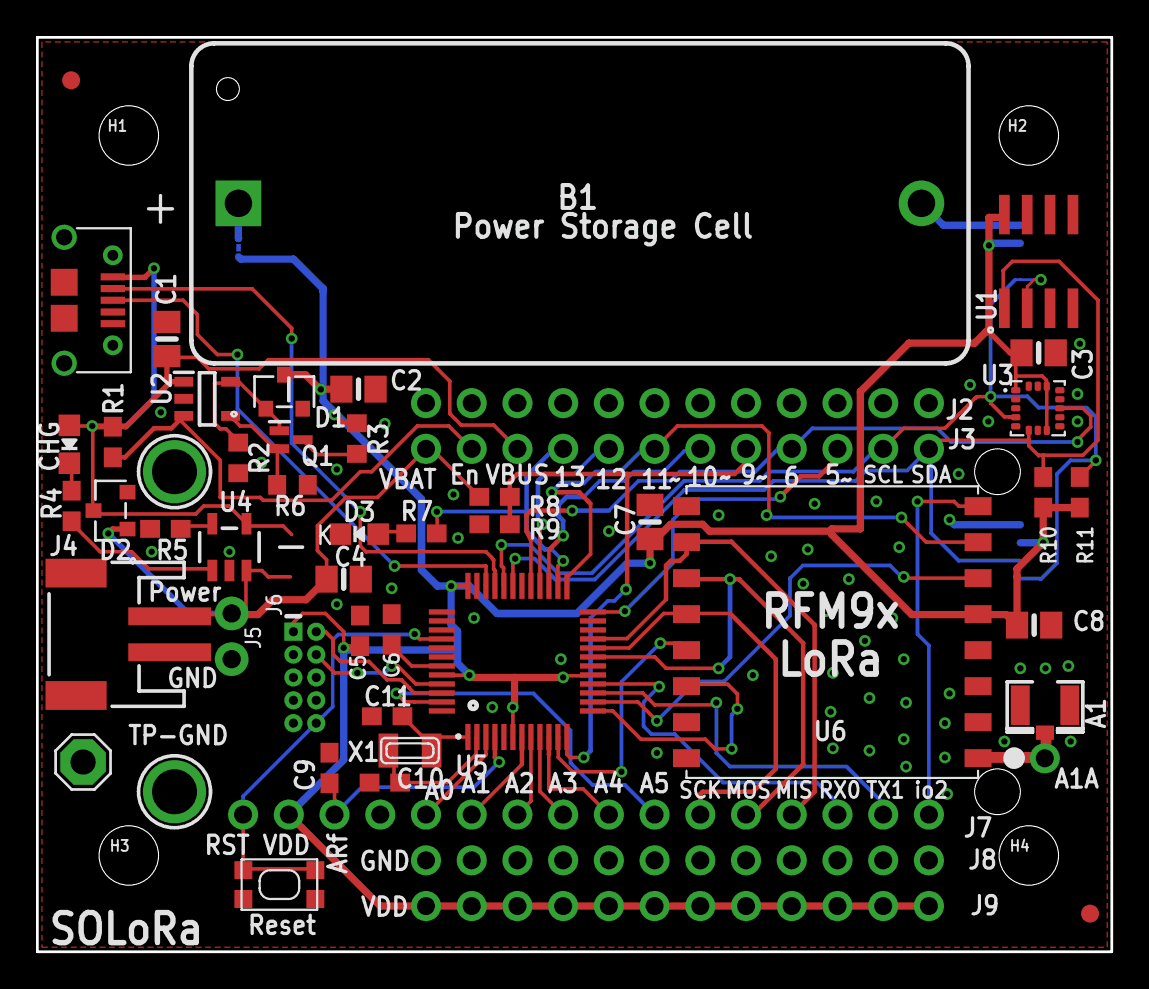
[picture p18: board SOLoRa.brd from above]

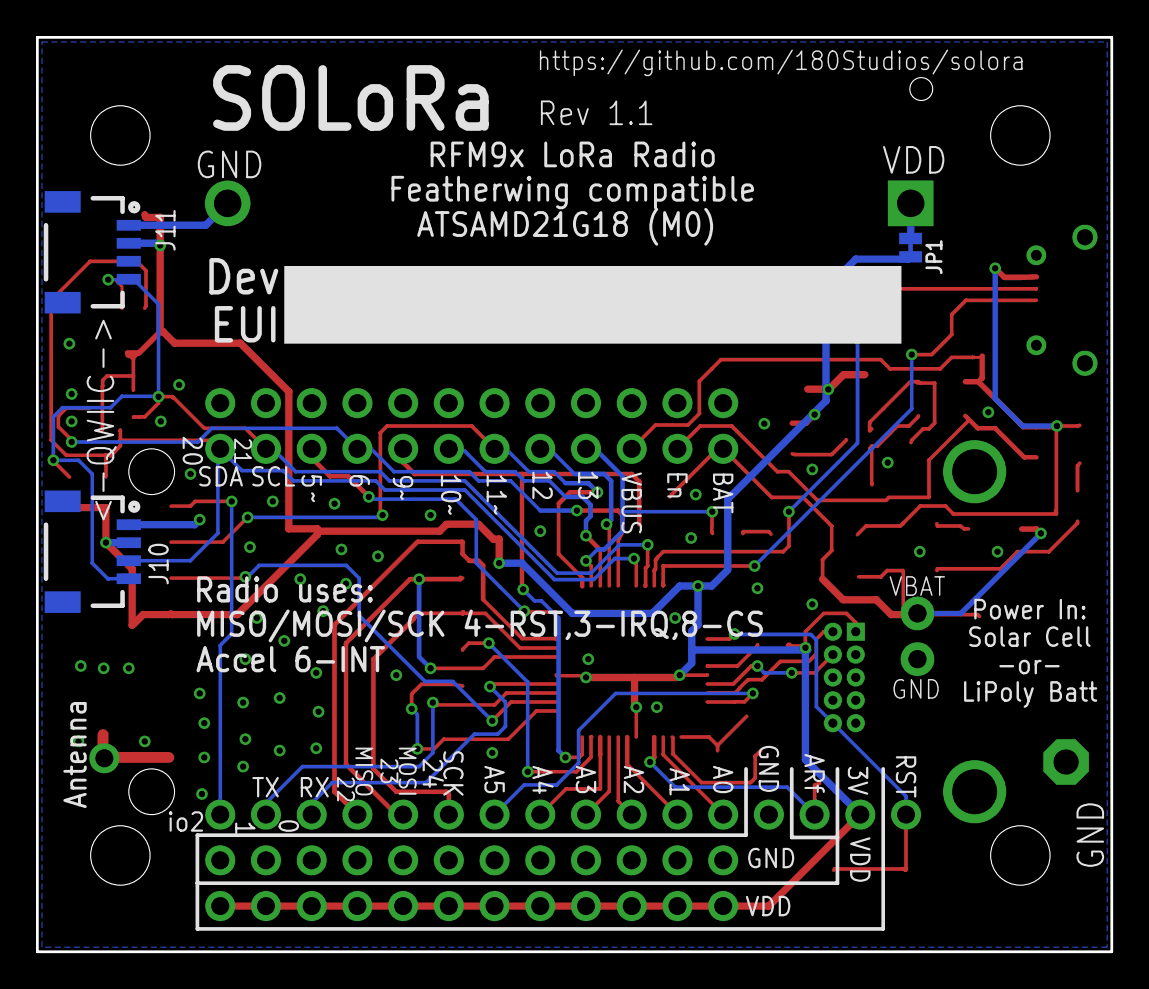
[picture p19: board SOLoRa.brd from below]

Board: 2 copper layers, 59.7 x 50.8 mm, 59 parts (3 on the bottom side), 47 nets.

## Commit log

2018-07-04 Added first draft BOM
    [SOLoRa_PCA_BOM_V1.0.xlsx]
2018-07-05 cosmetic changes to schematic
    [SOLoRa.sch]
2018-08-15 Version 1.1
    [SOLoRa.GBL, SOLoRa.GBO, SOLoRa.GBP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]

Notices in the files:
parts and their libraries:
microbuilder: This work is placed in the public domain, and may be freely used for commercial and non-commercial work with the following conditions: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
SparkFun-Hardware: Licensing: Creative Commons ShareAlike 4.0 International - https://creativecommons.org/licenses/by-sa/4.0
